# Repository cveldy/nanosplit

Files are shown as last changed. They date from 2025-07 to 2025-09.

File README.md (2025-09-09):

# nanosplit

Leverless (Hitbox-style) fighting game controller with a split-hand design using Cherry MX Ultra Low Profile (ULP) switches.

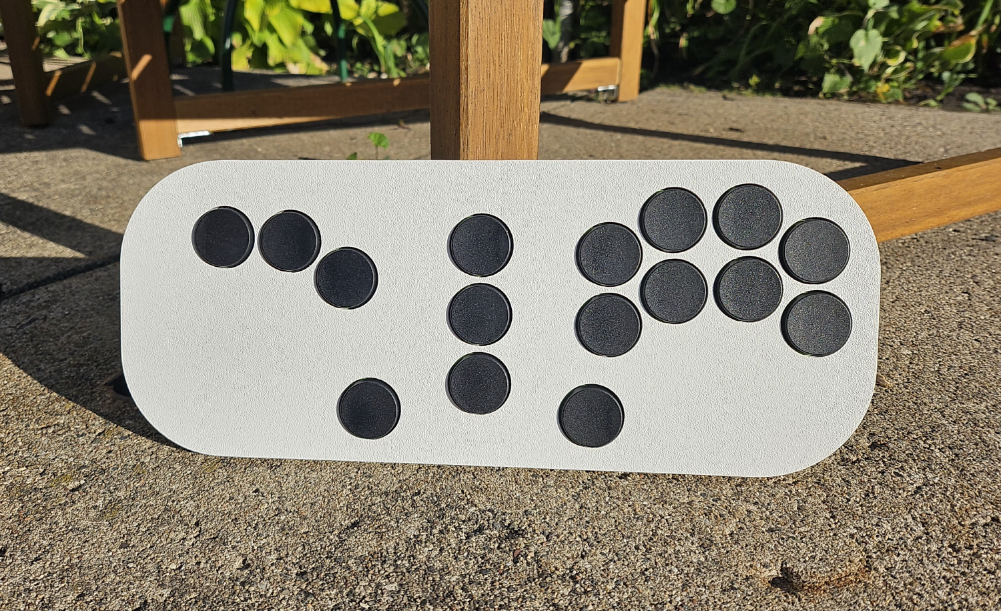
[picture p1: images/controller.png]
Front view of the nanosplit controller


## About

Fully assembled, dimensions are `304 x 124 x 9.8mm` (including bolts and non-slip pads, `8.6mm` without).

Powering this device is OpenStick's excellent [GP2040-CE](https://github.com/OpenStickCommunity/GP2040-CE) gamepad firmware. Please see that repository for information about configuration, console compatibility, and all the rest.

The ultra-short scissor switches used by this controller (which I believe are primarily intended for laptop keyboards) have an extremely tactile action and are somewhat harder to depress than standard Sanwa arcade buttons. This makes their actuation feel very binary (either all-the-way down or all-the-way up), almost the complete opposite of the smooth feel of traditional arcade buttons. Experientially, I have found them to be very divisive: people either love or hate the way they feel. If possible, I recommend trying them (say, by borrowing a friend's MPress Nano at your local) before committing to a full build.

## Creation

If you want to produce one, you will need some parts.

### PCB

- 1x nanosplit PCB, created using the files in the `prod/pcb/` directory with an online PCB prototyping service. (e.g., [JLCPCB](https://jlcpcb.com/).) Productions requires assembly with SMD parts, so you'll need to include the Gerbers, BOM, and CPL files.
  - If you are unfamiliar with this process, I recommend following the PCB ordering steps from [this README](https://github.com/AlpenmeisterCustoms/MeisterboxS).
- 16x Cherry MX Ultra Low Profile Switches. (I used Tactile, but you could use Clicky if you want.)
  - I purchased mine [from this German parts supplier](https://www.reichelt.com/us/en/shop/product/cherry_mx_ultra_low_profile_rgb_pushbutton_module-335042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), though they don't seem to be available at that URL anymore.

### Keycaps

- 16x [MPress Nano Caps](https://paradisearcadeshop.com/collections/mpress-nano) from Paradise Arcade Shop.

### Case

- 1x [3d-Printed Case](./prod/case/nochamfer.stl)
  - I don't personally own a 3d printer, but mine came out pretty nicely using [Craftcloud](https://craftcloud3d.com/) in ABS plastic at 60% infil (though in retrospect I may have chosen 80%).
- 1x each [Acrylic "Washer" Layer](./prod/case/acrylic_layer0_1mm.dxf) and [Acrylic Bottom Panel](./prod/case/acrylic_layer1_1mm.dxf) laser cut from `1mm` acrylic.
  - I ordered these online from [Ponoko](https://www.ponoko.com/) in clear.
- OPTIONAL: Non-slip Feet or Pads.
  - I used a few pieces cut from one of [these rolls of adhesive-backed silicon](https://www.amazon.com/dp/B09VFB7QVF).
- 8x M3-0.5 3.85mm Heat-set Threaded Inserts.
  - I ordered [these exact ones](https://www.amazon.com/dp/B077CL322T).
- 8x M3x6mm Bolts.
  - I ordered [these ultra-thin flat capped bolts](https://www.amazon.com/dp/B0C5M7M6ZM).

### Assembly

- Soldering Equipment.
- M2.5 Allen Key.

### Firmware

- The Latest [GP2040-CE Firmware for the Flatbox Rev4](https://github.com/OpenStickCommunity/GP2040-CE/releases/download/v0.7.11/GP2040-CE_0.7.11_FlatboxRev4.uf2), flashed according to the documentation.
- Pin (Button) Mapping using GP2040-CE's [Web Configurator](https://gp2040-ce.info/#/web-configurator)
  - There is a catch: the firmware assumes a default pin mapping that the nanosplit does not use. Until you've remapped the pins, you must hold down `Fn` (Function) (the bottom-most button in the central line) instead of `S2` (Start) when plugging in the controller to enter the configurator.
  - You could also short those switch contacts to ground manually if you haven't installed the switches yet when setting up the firmware.
  - After updating the pin mapping in the configurator, you'll hold `S2` to while plugging the device in to reach the configurator, like normal.
  - The correct mapping for the nanosplit is shown below.

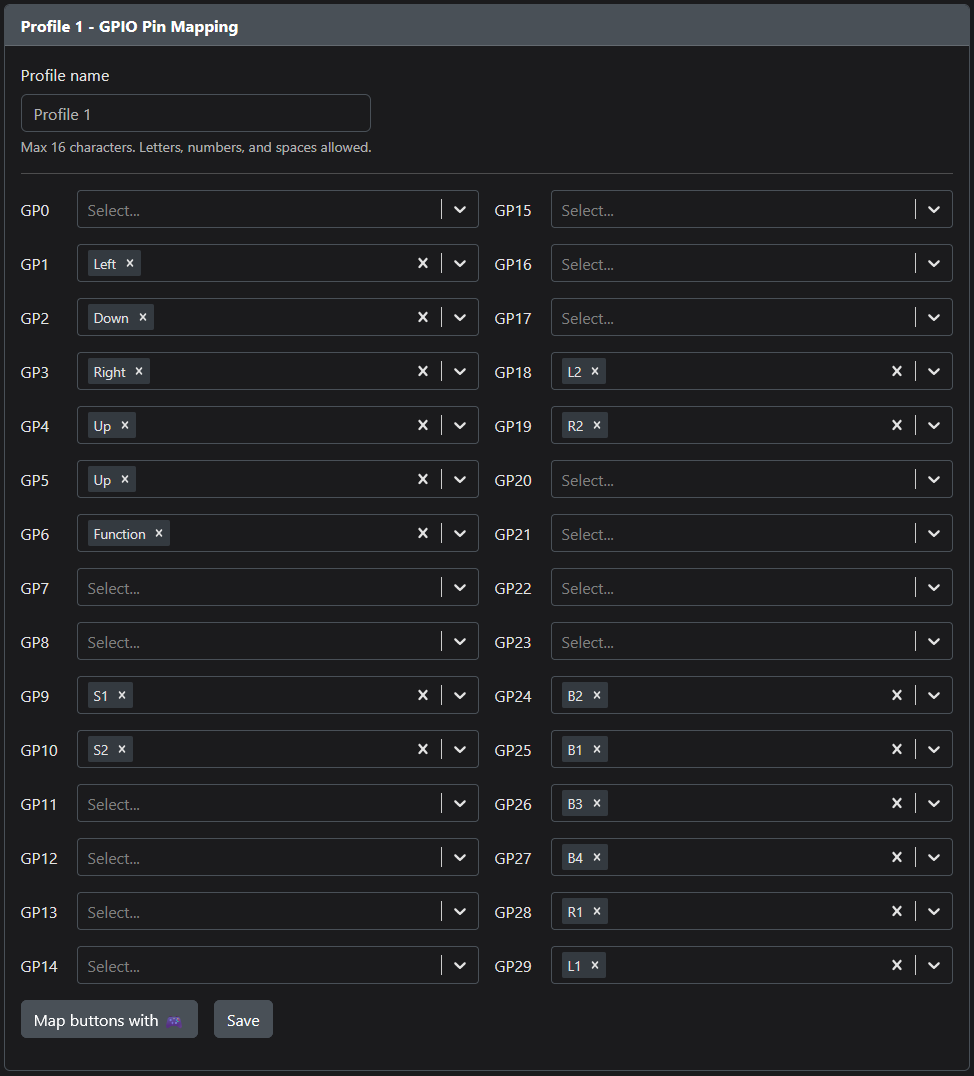
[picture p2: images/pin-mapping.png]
Default pip mapping in the GP2040 Web Configurator


- This controller makes `A1` (Guide), `A2` (Touchpad), `L3`, and `R3` available via a layer using the `Fn` (Function) switch (the bottom-most of the central 3).
- Shown below are the recommended function mappings, though you may prefer to use your own.

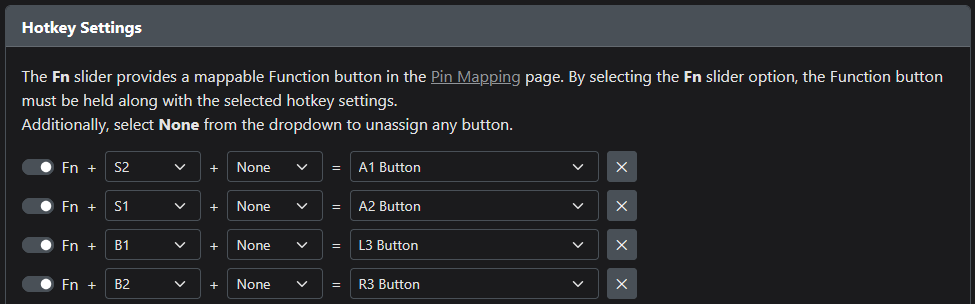
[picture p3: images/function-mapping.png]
Default function shortcuts in the GP2040 Web Configurator


### Art

You can use [this template](./prod/art/template_A3_300dpi.psd) to place artwork into a printable template with outlines showing where to cut. The template is sized to A3 paper and set for 300dpi. Once printed and cut, the art slots between the two acrylic lays on the *bottom* of the controller.

## License

PCB and case designs licensed under [CC BY-SA 4.0](https://creativecommons.org/licenses/by/4.0/).

## Acknowledgments

- [GrooveBob](https://github.com/GroooveBob)'s [Stress](https://github.com/GroooveBob/Stress), which helped inspire this design.
- [Paradise Arcade](https://paradisearcadeshop.com/)'s [MPress Nano](https://paradisearcadeshop.com/products/mpress-nano-leverless-gaming-controller), which helped inspire this design.
- [jfedor2](https://github.com/jfedor2)'s [Flatbox](https://github.com/jfedor2/flatbox), whose RP2040 implementation I recreated. [CC BY-SA 4.0](https://creativecommons.org/licenses/by/4.0/).
- [ruiqimao](https://github.com/ruiqimao)'s [Keyboard PCB Guide](https://github.com/ruiqimao/keyboard-pcb-guide), which led me through the entire PCB creation process.
- [pashutk](https://github.com/pashutk)'s [Cherry_MX_ULP](https://github.com/pashutk/Cherry_MX_ULP) repository and links, whose footprints are present in the PCB design and whose README gave me the confidence to try hand-soldering these normally-SMD switches.
- [Sadek Baroudi](https://github.com/sadekbaroudi)'s [Keyboard Case Design](https://kbd.news/Keyboard-Case-Design-1764.html) article, which showed the process for exporting the PCB into a form usable during case design.
- [OpenStickCommunity](https://github.com/OpenStickCommunity)'s [GP2040-CE](https://github.com/OpenStickCommunity/GP2040-CE), whose firmware makes the silicon useful and whose Discord community was extremely helpful.

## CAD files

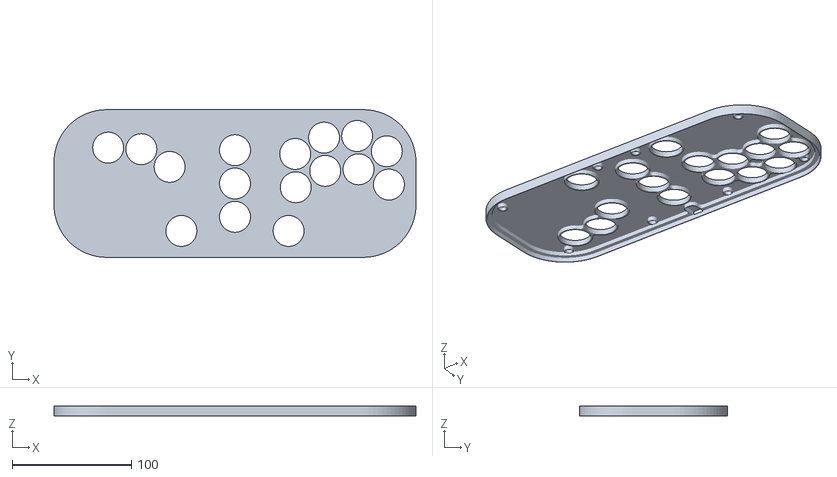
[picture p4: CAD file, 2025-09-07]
prod/case/nochamfer.stl
304.0 x 124.0 x 8.10

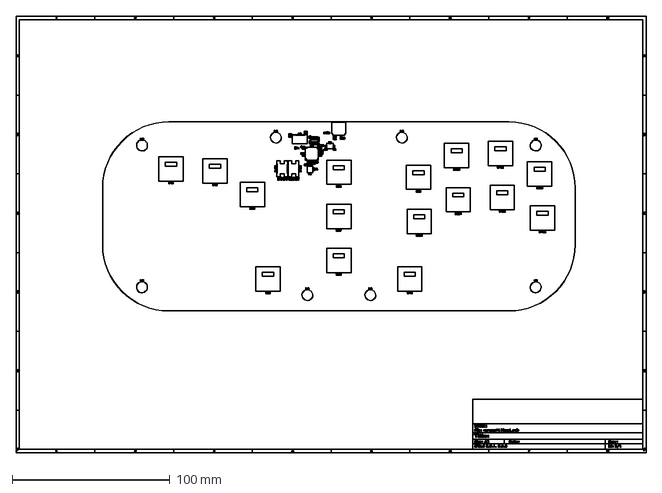
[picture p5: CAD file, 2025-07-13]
src/kicad/nanosplit-brd.dxf
400.0 x 277.0 mm

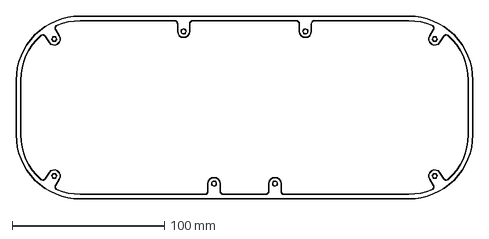
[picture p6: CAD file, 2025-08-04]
prod/case/acrylic_layer0_1mm.dxf
300.0 x 120.0 mm

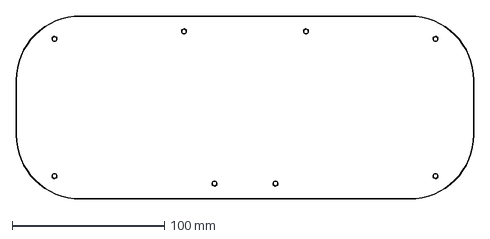
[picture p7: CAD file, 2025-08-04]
prod/case/acrylic_layer1_1mm.dxf
300.0 x 120.0 mm

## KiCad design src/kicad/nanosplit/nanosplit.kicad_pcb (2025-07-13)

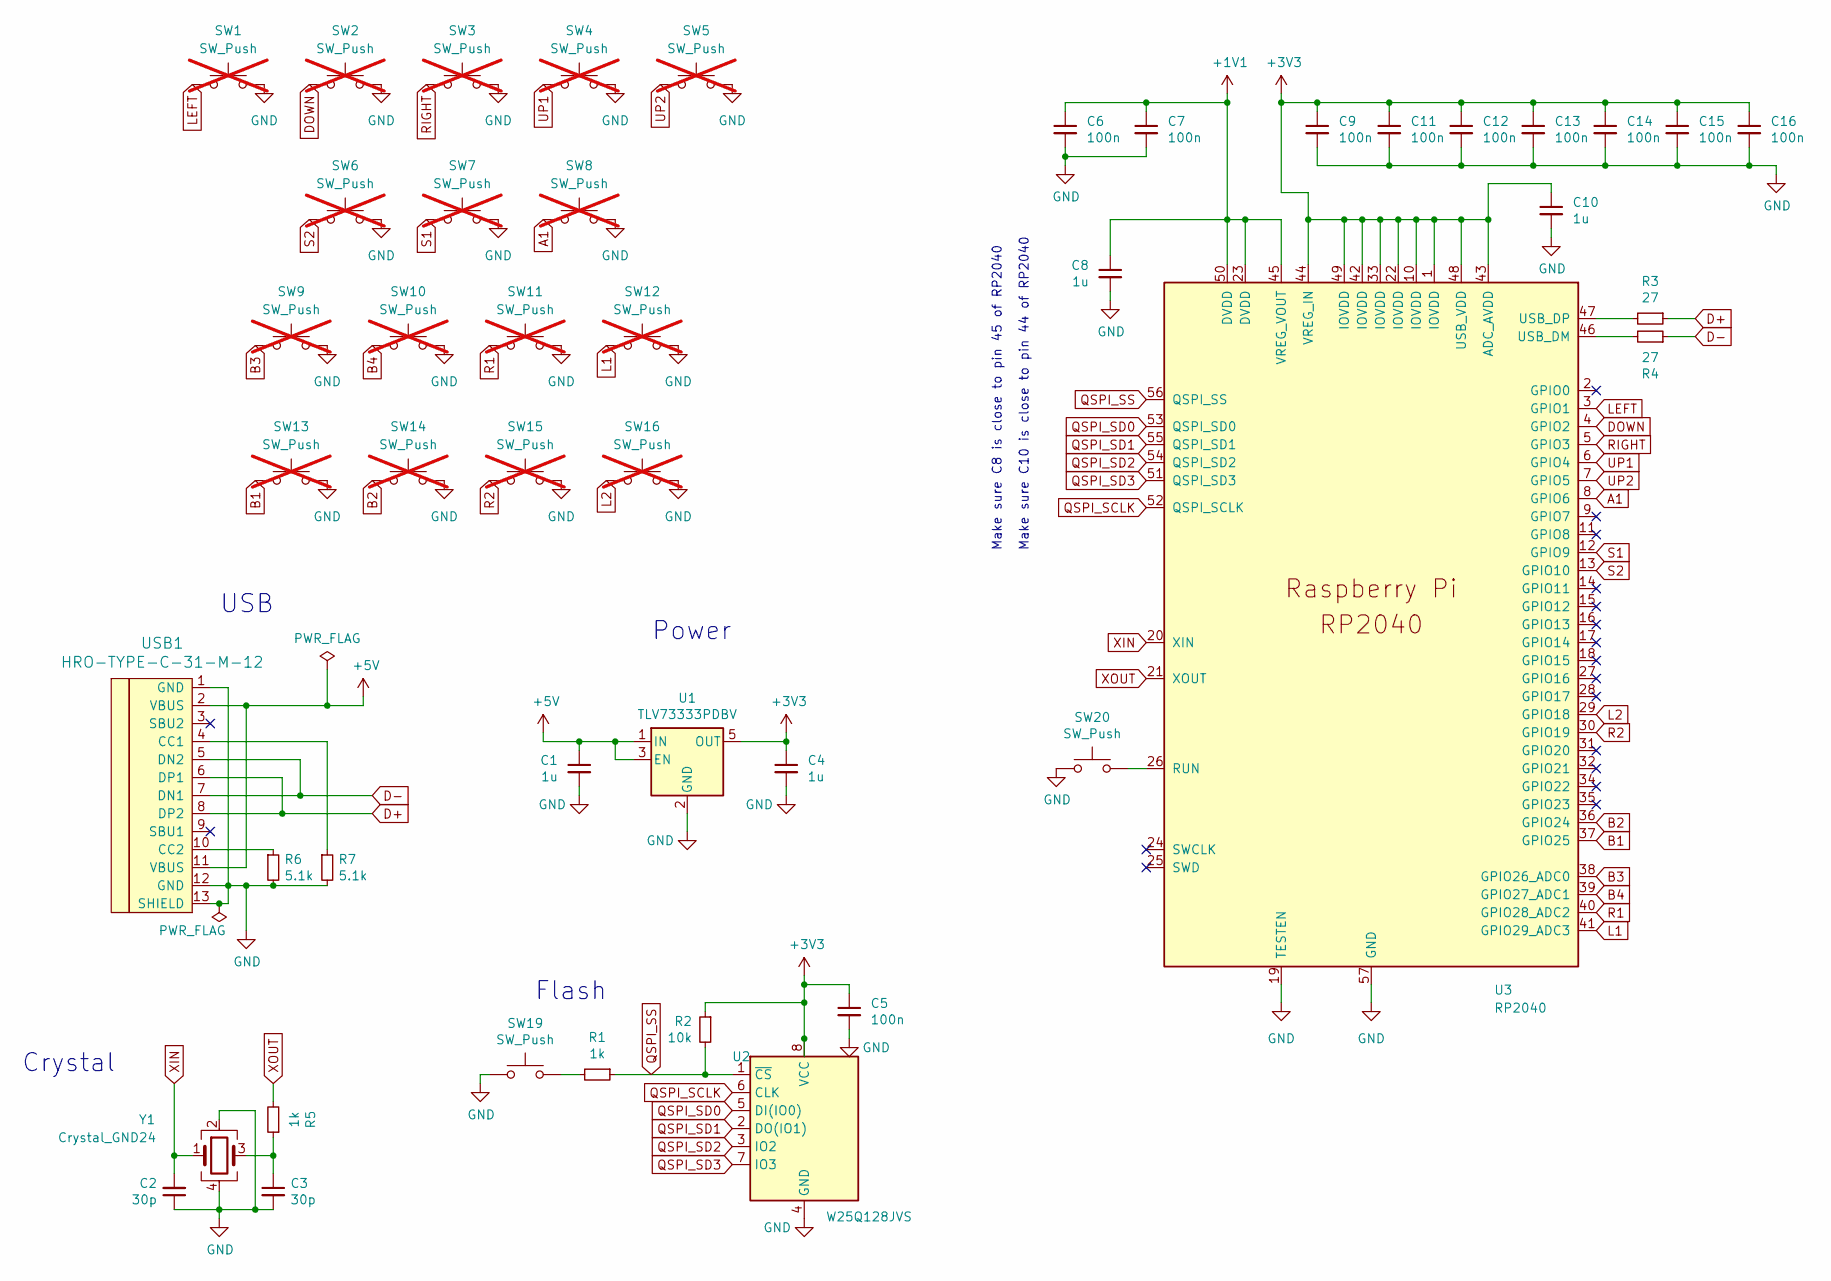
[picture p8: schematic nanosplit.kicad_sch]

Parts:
C1, C4, C8, C10: 1u; C_0402_1005Metric; LCSC C52923
C2, C3: 30p; C_0402_1005Metric; LCSC C1570
C5, C6, C7, C9, C11, C12, C13, C14, C15, C16: 100n; C_0402_1005Metric; LCSC C1525
R1, R5: 1k; R_0402_1005Metric; LCSC C11702
R2: 10k; R_0402_1005Metric; LCSC C25744
R3, R4: 27; R_0402_1005Metric; LCSC C138021
R6, R7: 5.1k; R_0402_1005Metric; LCSC C25905
SW1, SW2, SW3, SW4, SW5, SW6, SW7, SW8, SW9, SW10, SW11, SW12, SW13, SW14, SW15, SW16: SW_Push; Cherry_ULP_TH; not fitted
SW19, SW20: SW_Push; SW_SPST_Omron_B3FS-100xP; LCSC C271750
U1: TLV73333PDBV; SOT-23-5; LCSC C134139
U2: W25Q128JVS; SOIC-8_5.23x5.23mm_P1.27mm; LCSC C97521
U3: RP2040; RP2040-QFN-56; LCSC C2040
USB1: HRO-TYPE-C-31-M-12; HRO-TYPE-C-31-M-12-Assembly; LCSC C165948
Y1: Crystal_GND24; Crystal_SMD_3225-4Pin_3.2x2.5mm; LCSC C9002

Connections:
+1V1: C6.1, C7.1, C8.1, U3.23 (DVDD), U3.45 (VREG_VOUT), U3.50 (DVDD)
+3V3: C4.1, C5.1, C9.1, C10.1, C11.1, C12.1, C13.1, C14.1, C15.1, C16.1, R2.1, U1.5 (OUT), U2.8 (VCC), U3.1 (IOVDD), U3.10 (IOVDD), U3.22 (IOVDD), U3.33 (IOVDD), U3.42 (IOVDD), U3.43 (ADC_AVDD), U3.44 (VREG_IN), U3.48 (USB_VDD), U3.49 (IOVDD)
+5V: C1.1, U1.1 (IN), U1.3 (EN), USB1.2 (VBUS), USB1.11 (VBUS)
A1: SW8.1, U3.8 (GPIO6)
B1: SW13.1, U3.37 (GPIO25)
B2: SW14.1, U3.36 (GPIO24)
B3: SW9.1, U3.38 (GPIO26_ADC0)
B4: SW10.1, U3.39 (GPIO27_ADC1)
D+: R3.1, USB1.6 (DP1), USB1.8 (DP2)
D-: R4.1, USB1.5 (DN2), USB1.7 (DN1)
DOWN: SW2.1, U3.4 (GPIO2)
GND: C1.2, C2.1, C3.2, C4.2, C5.2, C6.2, C7.2, C8.2, C9.2, C10.2, C11.2, C12.2, C13.2, C14.2, C15.2, C16.2, R6.2, R7.2, SW1.2, SW2.2, SW3.2, SW4.2, SW5.2, SW6.2, SW7.2, SW8.2, SW9.2, SW10.2, SW11.2, SW12.2, SW13.2, SW14.2, SW15.2, SW16.2, SW19.1, SW20.1, U1.2 (GND), U2.4 (GND), U3.19 (TESTEN), U3.57 (GND), USB1.1 (GND), USB1.12 (GND), USB1.13 (SHIELD), Y1.2, Y1.4
L1: SW12.1, U3.41 (GPIO29_ADC3)
L2: SW16.1, U3.29 (GPIO18)
LEFT: SW1.1, U3.3 (GPIO1)
unnamed: C3.1, R5.1, Y1.3
unnamed: R1.2, SW19.2
unnamed: SW20.2, U3.26 (RUN)
unnamed: R4.2, U3.46 (USB_DM)
unnamed: R3.2, U3.47 (USB_DP)
unnamed: R7.1, USB1.4 (CC1)
unnamed: R6.1, USB1.10 (CC2)
QSPI_SCLK: U2.6 (CLK), U3.52 (QSPI_SCLK)
QSPI_SD0: U2.5 (DI(IO0)), U3.53 (QSPI_SD0)
QSPI_SD1: U2.2 (DO(IO1)), U3.55 (QSPI_SD1)
QSPI_SD2: U2.3 (IO2), U3.54 (QSPI_SD2)
QSPI_SD3: U2.7 (IO3), U3.51 (QSPI_SD3)
QSPI_SS: R1.1, R2.2, U2.1 (~CS), U3.56 (QSPI_SS)
R1: SW11.1, U3.40 (GPIO28_ADC2)
R2: SW15.1, U3.30 (GPIO19)
RIGHT: SW3.1, U3.5 (GPIO3)
S1: SW7.1, U3.12 (GPIO9)
S2: SW6.1, U3.13 (GPIO10)
UP1: SW4.1, U3.6 (GPIO4)
UP2: SW5.1, U3.7 (GPIO5)
XIN: C2.2, U3.20 (XIN), Y1.1
XOUT: R5.2, U3.21 (XOUT)

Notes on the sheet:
USB
Make sure C10 is close to pin 44 of RP2040
Make sure C8 is close to pin 45 of RP2040
Power
Crystal
Flash

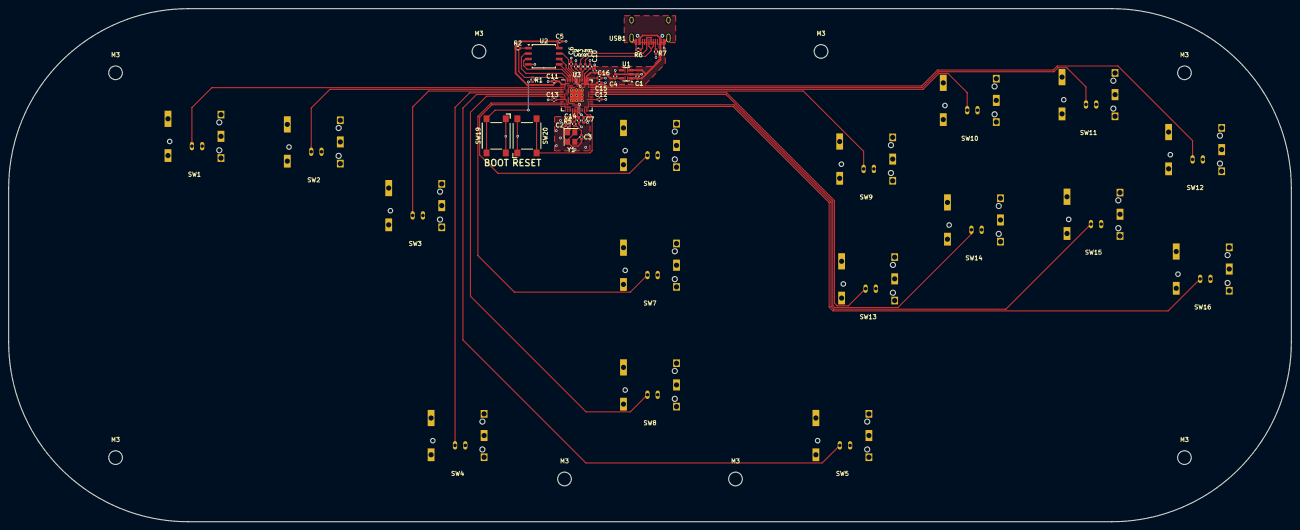
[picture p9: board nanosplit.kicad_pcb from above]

Board: 2 copper layers, 300.0 x 120.0 mm, 54 parts (0 on the bottom side), 37 nets.

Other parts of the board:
M3, M3#2, M3#3, M3#4, M3#5, M3#6, M3#7, M3#8: MountingHole_3.2mm_M3

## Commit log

2025-07-13 Added PCB production files!
    [nanosplit-B_Cu.gbl, nanosplit-B_Mask.gbs, nanosplit-B_Paste.gbp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]
2025-08-04 First versions of case files.
    [acrylic_layer0_1mm.dxf, acrylic_layer1_1mm.dxf, chamfer.stl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]
2025-09-07 Final assembled version. (TODO: Art and an image for the README)
    [chamfer.stl, nochamfer-flip.stl, nochamfer.stl]
